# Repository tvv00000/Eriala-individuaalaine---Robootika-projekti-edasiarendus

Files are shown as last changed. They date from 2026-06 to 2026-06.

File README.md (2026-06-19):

MDTJF 2000

MDTJF 2000 on interaktiivne tuumareaktori simulaator. Projekt kasutab füüsilisi juhtpaneele, ekraane, LED-indikaatoreid ja helisignaale, et simuleerida reaktori käivitamist, juhtimist, jahutamist ning elektritootmist.

- `src/` – tarkvara
- `docs/` – juhendid ja tehniline info
- `hardware/` – elektroonika ja skeemid
- `media/` – demonstratsioonid

[demovideo](https://drive.google.com/file/d/1ct23M7h8ehWZ-KBIECmZKTh7m00w4W7L/view?usp=drive_link)

[WOWKWI link simulaatorile ja skeemile](https://wokwi.com/projects/448691473688261633)

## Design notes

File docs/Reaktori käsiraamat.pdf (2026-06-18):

# MDTJF 2000 Reaktori käsiraamat

# Sisukord

Sisukord | 2
Seadme kirjeldus | 3
Paneelide kirjeldused | 4
Fuel Control | 4
Control Rods | 5
Coolant Control | 6
Turbine | 7
Warnings | 8
Protseduurid | 9
Setup | 9
Startup protseduur | 9
Tööprotseduur | 9
Hädaolukorra protseduur | 9
Metainfo | 9

# Seadme kirjeldus

MDTJF 2000 on vesijahtusega, grafiidiga modereeritud väikereaktor. Selle veemahutavus on 2000l ning ettenähtud tööpiirkonnas ta toodab 500-2000MW energiat reaktiivsuse 2000-6000rad juures. Käesolev käsiraamat kirjeldab ära seadme elemendid ning ohutu kasutuse.

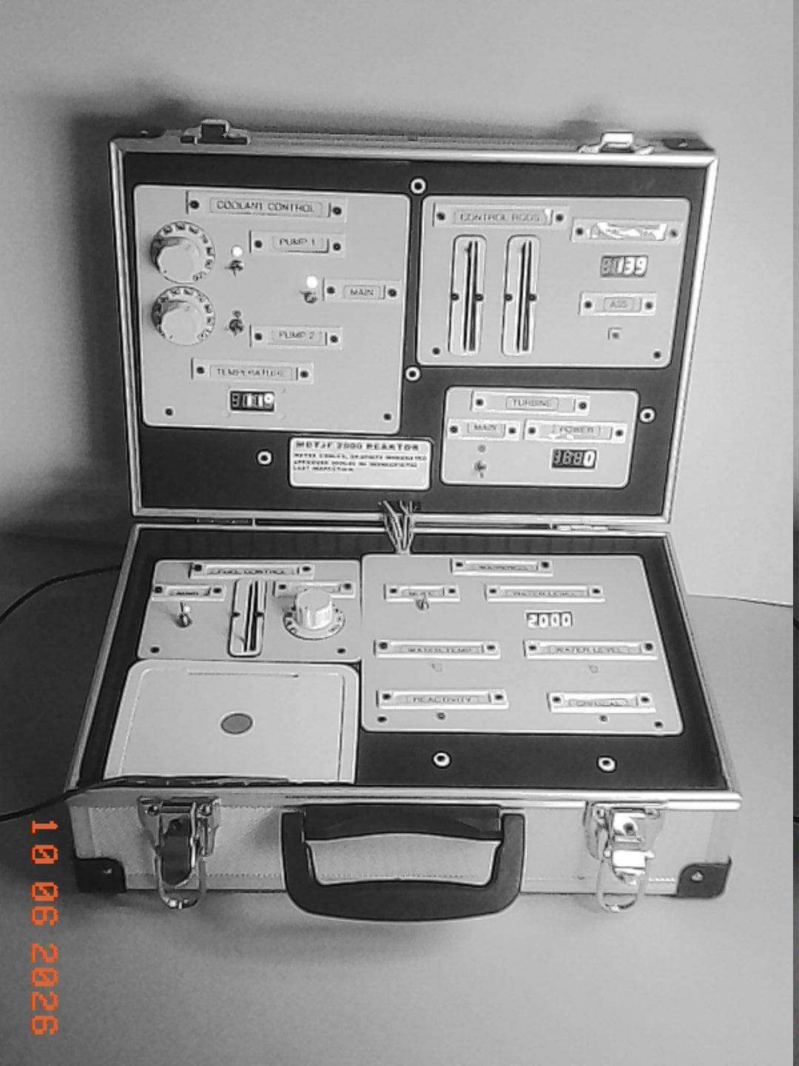
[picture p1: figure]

Pilt 1.1 - Reaktori Kontrollpaneelid

# Paneelide kirjeldused

## Fuel Control

Paneeli funktsioon
Paneel võimaldab juhtida reaktori kütusevarraste asendit ning seeläbi reguleerida tuumas toimuva ahelreaktsiooni intensiivsust. Kütusevarraste sisestamisel reaktori südamikku suureneb reaktsiooni aktiivsus, mille tulemusena eraldub rohkem soojust. Kütusevarraste väljatõmbamisel reaktsiooni intensiivsus väheneb.

Paneeli elementide kirjeldus
- Lüliti MAIN lülitab paneeli sisse/välja.
- Liugur FUEL CONTROL võimaldab muuta kütusevarraste asendit reaktoris.
- Pöördnupp TUNE võimaldab kütusevarraste asendit väikeste sammudega muuta.

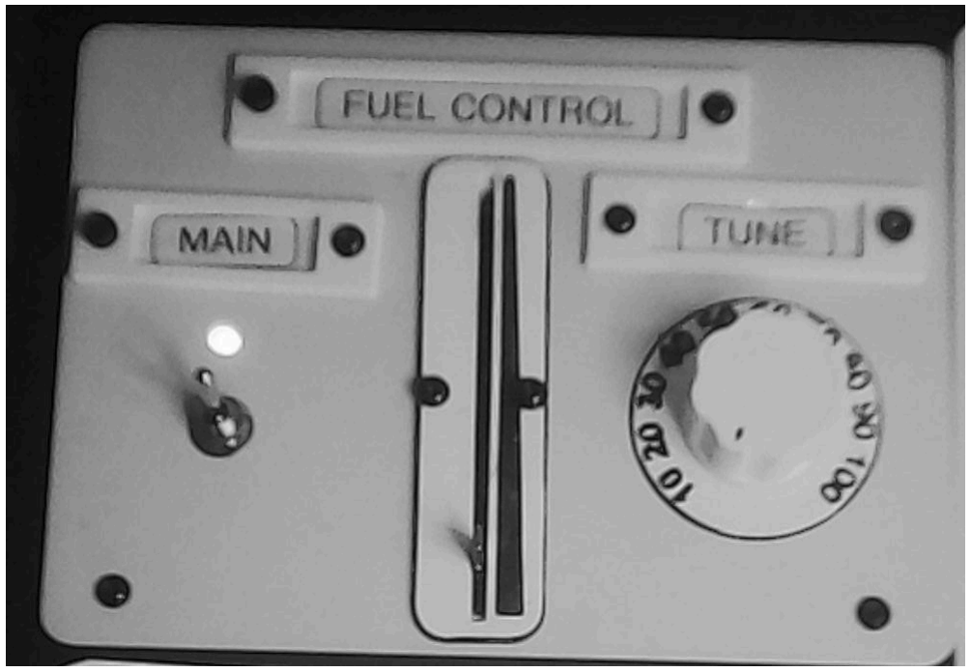
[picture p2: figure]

Pilt 1.2 - Fuel Control Paneel

## Control Rods

Paneeli funktsioon
Paneel võimaldab jälgida ja juhtida reaktori reaktiivsust kontrollvarraste abil. Kontrollvarraste liigutamisega saab reguleerida tuumas toimuva ahelreaktsiooni kiirust ning seeläbi mõjutada reaktori võimsust ja soojuseraldust. Hädaolukorras võimaldab nupp A35 algatada reaktori kiire seiskamise.

Paneeli elementide kirjeldus
- Ekraan REACTIVITY näitab reaktori hetkelise reaktiivsuse ehk ahelreaktsiooni intensiivsuse.
- CONTROL RODS vasak Liugur juhib ühe kolmandiku (1/3) kontrollvarraste asendit.
- CONTROL RODS parem Liugur juhib kahe kolmandiku (2/3) kontrollvarraste asendit.
- Nupp A35 käivitab hädaolukorras reaktori avariiseiskamise protseduuri; tõstab välja kütusevardad, sisestab kontrollvardad ning tõstab pumpade kiiruse maksimumini.

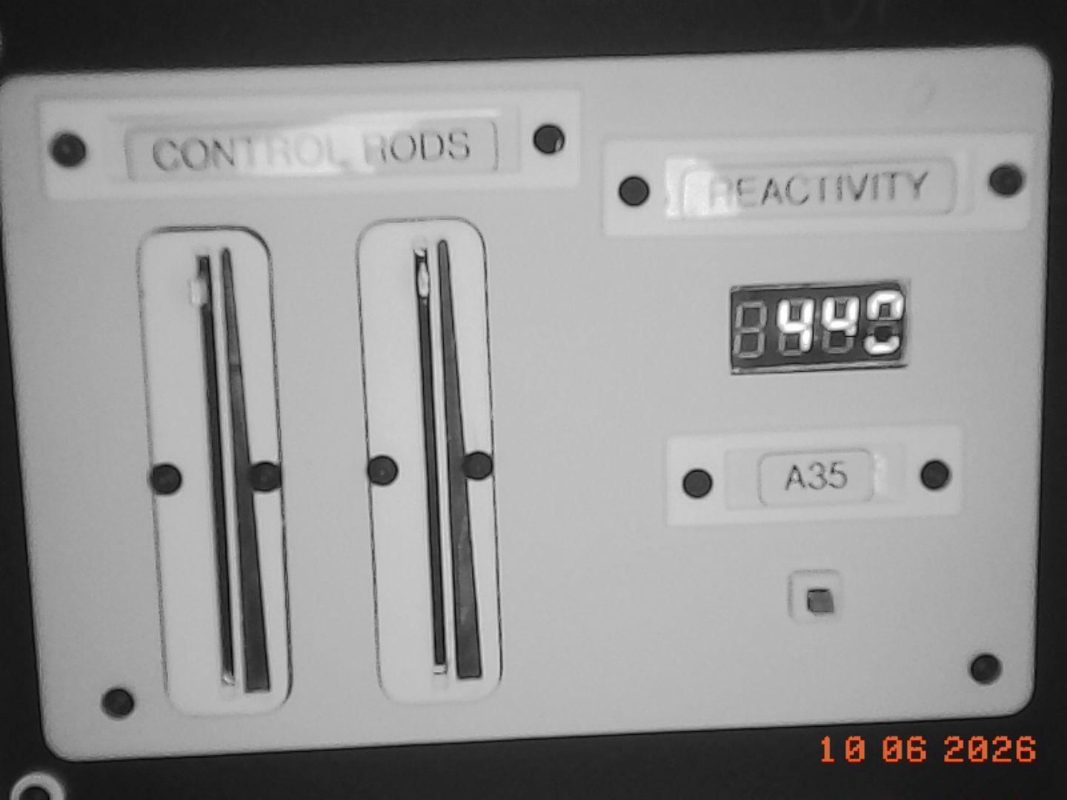
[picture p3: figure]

Pilt 1.3 - Control Rods Paneel

## Coolant Control

Paneeli funktsioon
Paneel võimaldab juhtida jahutussüsteemi pumpade tööd. Selle abil saab pumpasid sisse ja välja lülitada, reguleerida nende töökiirust ning jälgida reaktori veetemperatuuri. Pumpade ülesandeks on tagada tuuma pidev jahutamine ning kompenseerida süsteemist aurustunud vee kadu.

Paneeli elementide kirjeldus
- Lüliti MAIN lülitab paneeli sisse/välja.
- Lülitid PUMP 1 ja PUMP 2 lülitavad vastavad pumpad sisse/välja.
- Pöördnupud PUMP 1 ja PUMP 2 reguleerivad pumpade kiirust.
- Ekraan TEMPERATURE näitab hetke veetemperatuuri.

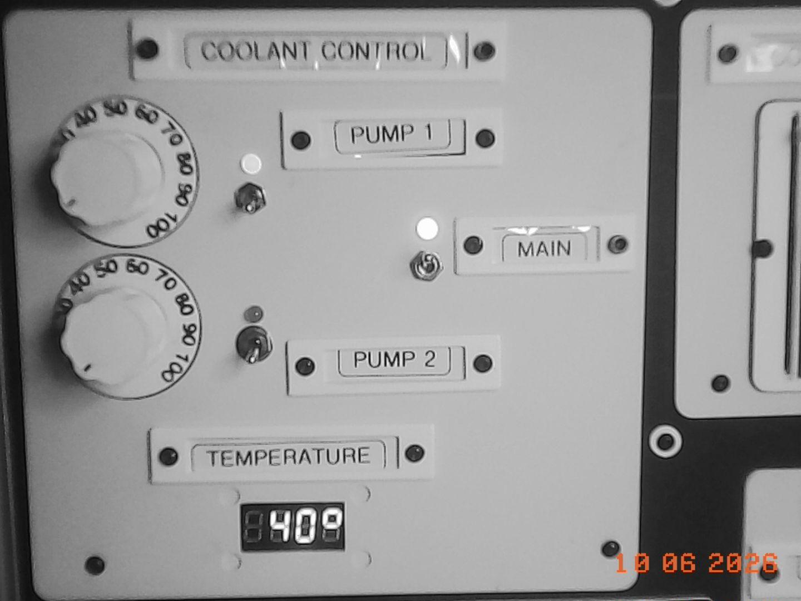
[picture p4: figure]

Pilt 1.4 - Coolant Control Paneel

## Turbine

Paneeli funktsioon
Paneel võimaldab juhtida elektritootmissüsteemi tööd ning jälgida reaktori poolt toodetavat võimsust.

Paneeli elementide kirjeldus
- Lüliti MAIN lülitab turbiinid sisse/välja.
- Ekraan POWER näitab reaktori hetkelise elektrilise võimsuse megavattides.

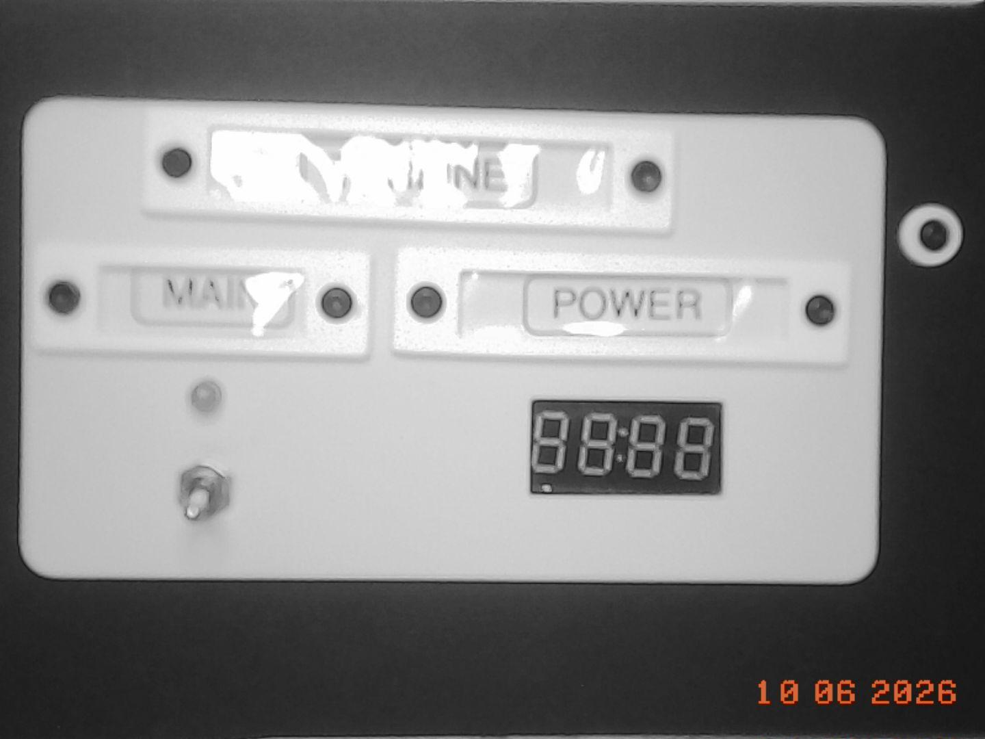
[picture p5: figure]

Pilt 1.5 - Turbine Paneel

## Warnings

Paneeli funktsioon
Paneel võimaldab jälgida reaktori peamisi tööparameetreid ning hoiatab operaatorit võimalike ohuolukordade eest. Selle abil saab jälgida veetaset ja temperatuuri reaktoris, reaktiivsust ja temperatuuri reaktoris ning vaigistada aktiivseid alarmsignaale.

Paneeli elementide kirjeldus
- Lüliti MUTE vaigistab alarmsignaalid.
- Ekraan WATER LEVEL näitab reaktori veetaseme liitrites.
- Märgutuli WATER TEMP süttib, kui vee temperatuur on alla/üle lubatud piirväärtuste (alla 10 kraadi või üle 95 kraadi)
- Märgutuli WATER LEVEL süttib, kui veetase reaktoris langeb ohtlikult madalale (alla 1500).
- Märgutuli REACTIVITY süttib, kui reaktori reaktiivsus ületab ohutud tööpiirid (üle 7000).
- Märgutuli CRITICAL süttib, kui reaktori südamiku temperatuur ületab ohutud piirväärtused.

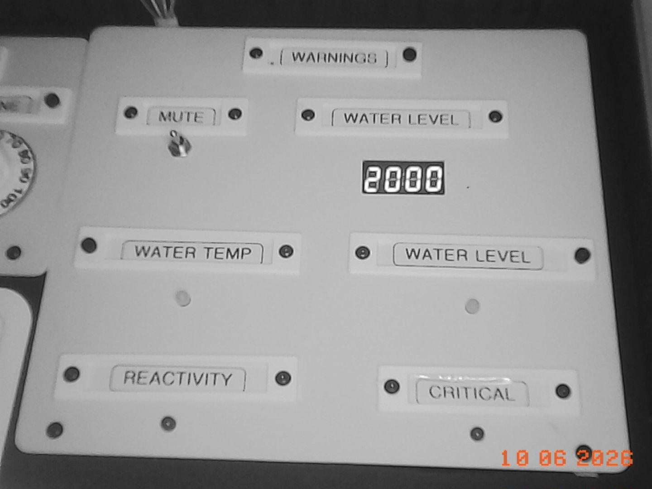
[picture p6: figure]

Pilt 1.6 - Warnings Paneel

# Protseduurid

## Setup

Kõik lülitid/nupud on väljas ja kõik liugurid (liuguril on 100 all ja 0 üleval) on 0s.

## Startup protseduur

1. Lülitada sisse pumba main.
2. Tõsta fuel control tune 50% peale.
3. Lülitada sisse fuel control main.
4. Aeglaselt liigutada kütusevarrast kuni reaktiivsuse ekraan hakkab tõusma.
5. Kui reaktiivsus on tõusnud üle 1000, võib vaikselt sisestada VASAKPOOLSET kontrollvarrast, et kontrollida reaktiivsuse kasvu tõusu.
6. Kui vasakpoolne kontrollvarras on 50% peal, hakata kasutama reaktsiooni kiiruse kontrolliks parempoolset varrast.
7. Kui vee temp jõuab 50c juurde, lülitada sisse pump 1.
8. Veetaseme vähenemisel, tõsta pump 1 kiirust, kuni veekadu lõppeb.
9. Olles jõudnud reaktiivsuseni 3500, hoida seda kuni vee temperatuur jõuba 70cni.
10. Lülitada sisse turbiin.

## Tööprotseduur

Kontrollida reaktsiooni kiirust kasutades kontrollvardaid ja kütusevardaid. Takistada vee kadu kasutades veepumpasid. Kui reaktor toodab energiat, siis veepumbad kasutavad reaktori toodetud energiat. Hoida energia tootlikkus 1500mw peal (+-500mw).

## Hädaolukorra protseduur

Olukorra kontrolli alt väljudes, lülitada sisse nupp A35. See nupp tõstab välja kütusevardad, sisestab kontrollvardad ning tõstab pumpade kiiruse maksimumini.

## Metainfo

Kui pole soovi kasutada veekeetjat, siis mitte pista see stepslisse. Kui tuuma temperatuur jõuab üle 900c või vee temperatuur üle 200c, siis seade teeb ise restarti, andes sellest teada ekraanil oleva tekstiga. Restardi algusest kuni lõpuni on 6 sekundit aega kõik juhtseadmed algasenditesse panna. fuel control main lüliti väljalülitamise järel ei saa restardi järel reaktor enam ise käivituda. Pumpade main väljalülitamise järel ei jahtu vee temperatuur samuti mitte. Reaktori seadeid saab tuunida parameetritega koodis. Kood on kommenteeritud.

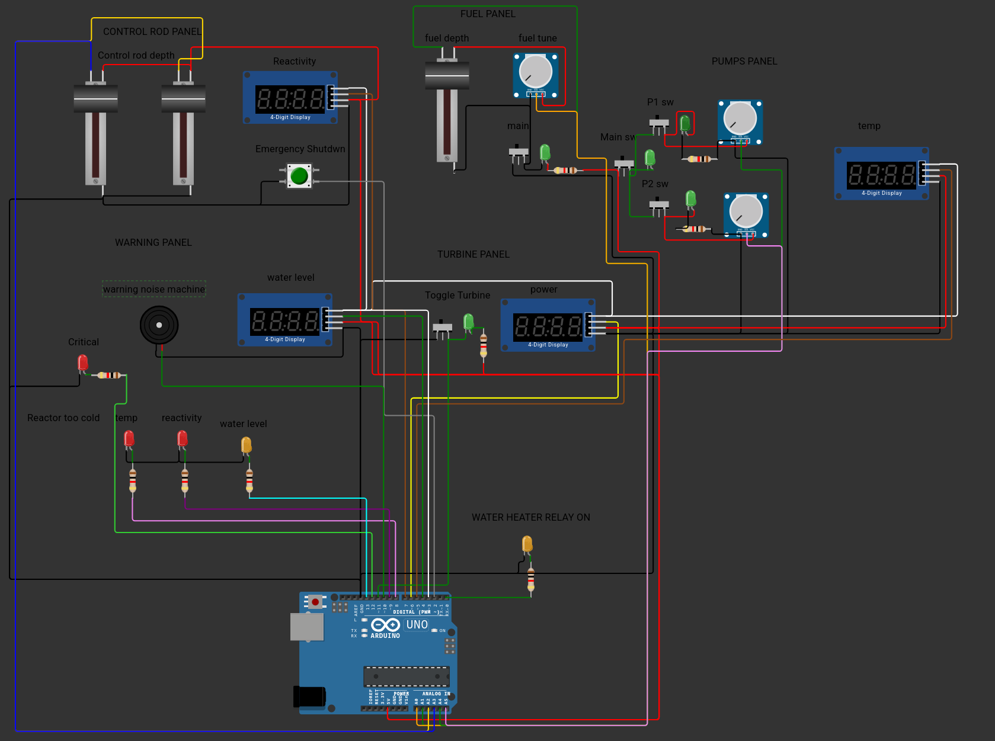
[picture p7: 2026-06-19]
hardware/Reaktor skeem.png

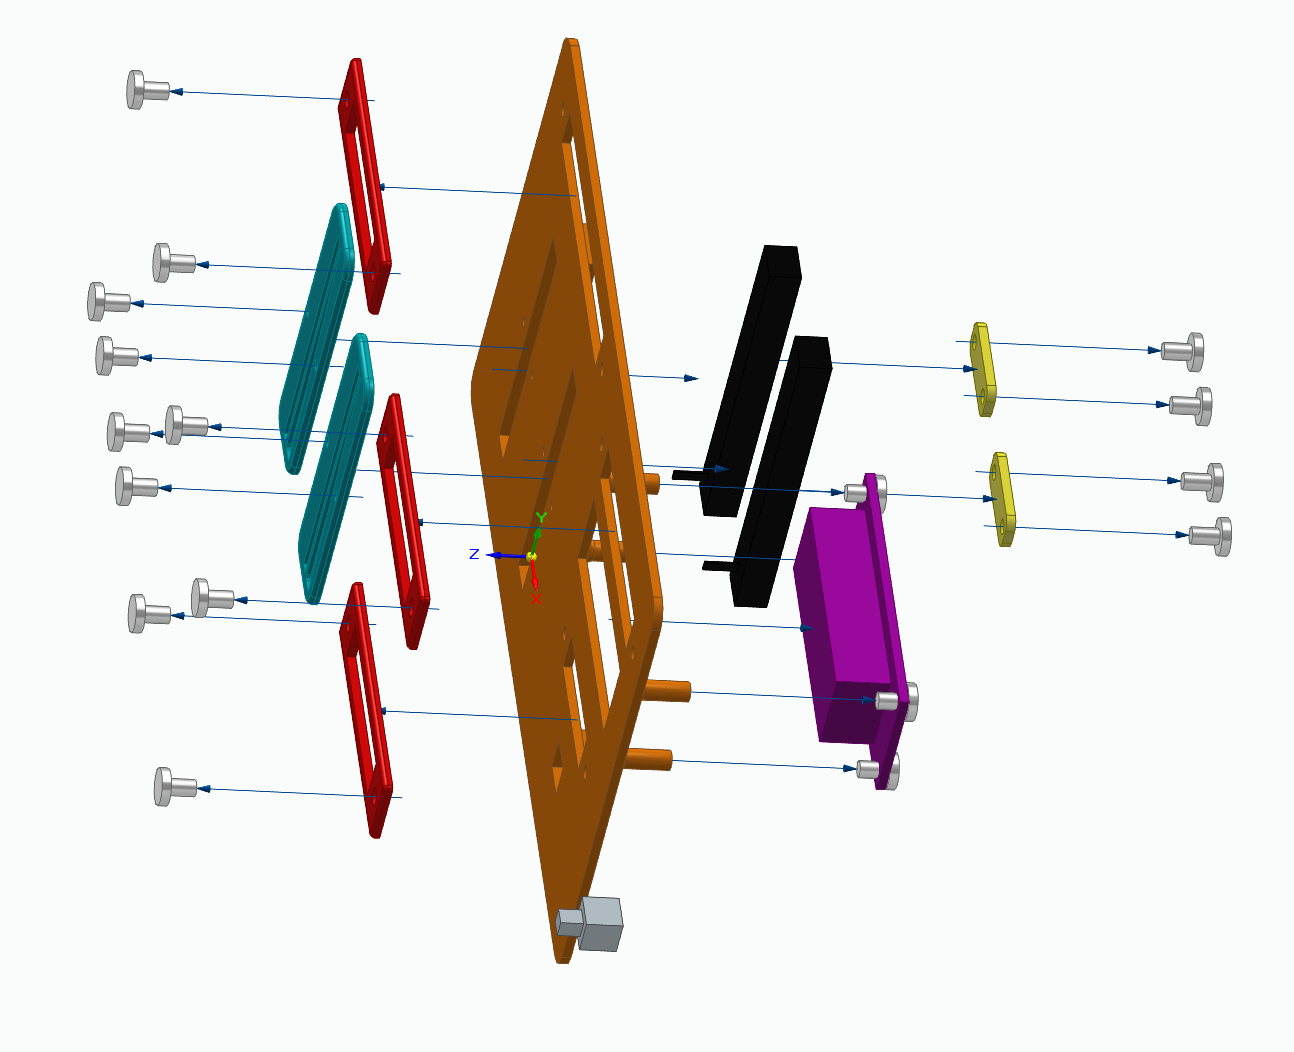
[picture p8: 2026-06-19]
docs/paneeli asm.PNG

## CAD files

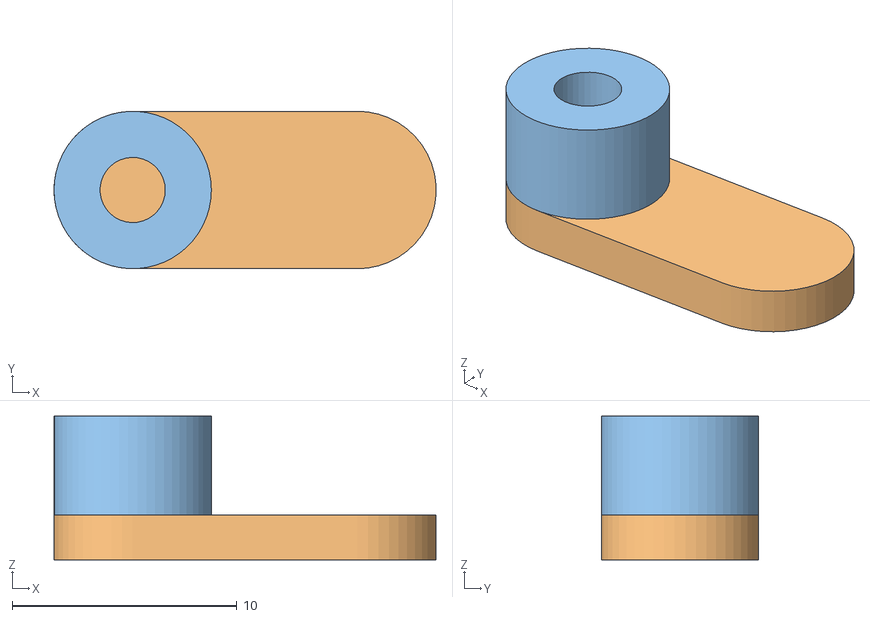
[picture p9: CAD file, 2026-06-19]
hardware/Mounting bracket.obj
17.0 x 7.00 x 6.40

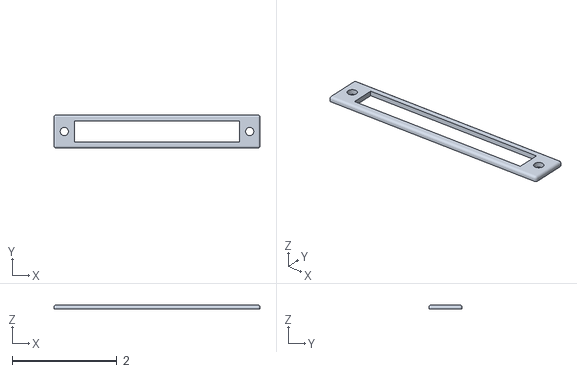
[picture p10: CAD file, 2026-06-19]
hardware/lable cover 80.stl
3.94 x 0.63 x 0.0787

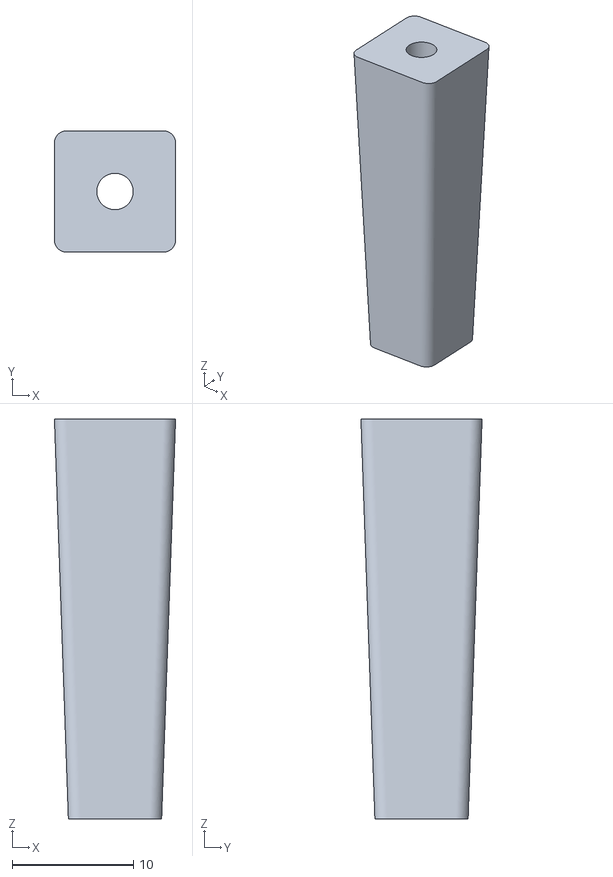
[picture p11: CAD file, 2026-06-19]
hardware/Panel Support 33mm.stl
10.0 x 10.0 x 33.0

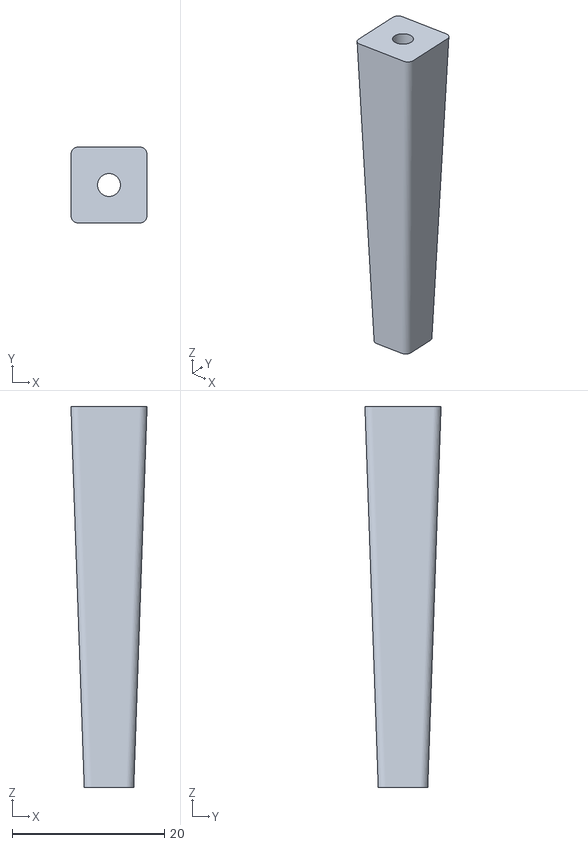
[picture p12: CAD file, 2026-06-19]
hardware/Panel Support 50mm.stl
10.0 x 10.0 x 50.0

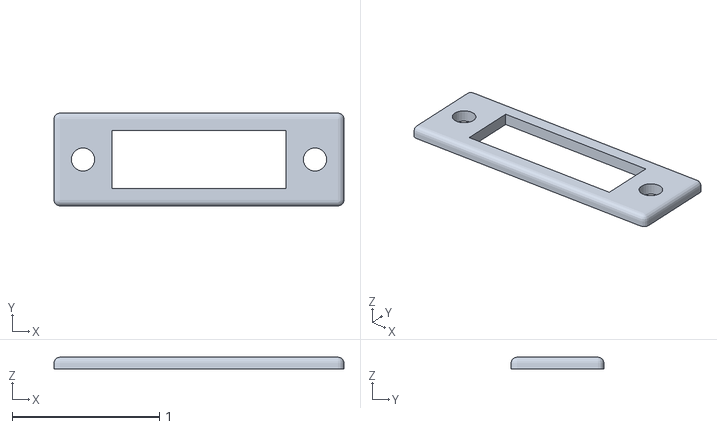
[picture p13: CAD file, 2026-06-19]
hardware/lable cover 30.stl
1.97 x 0.63 x 0.0787

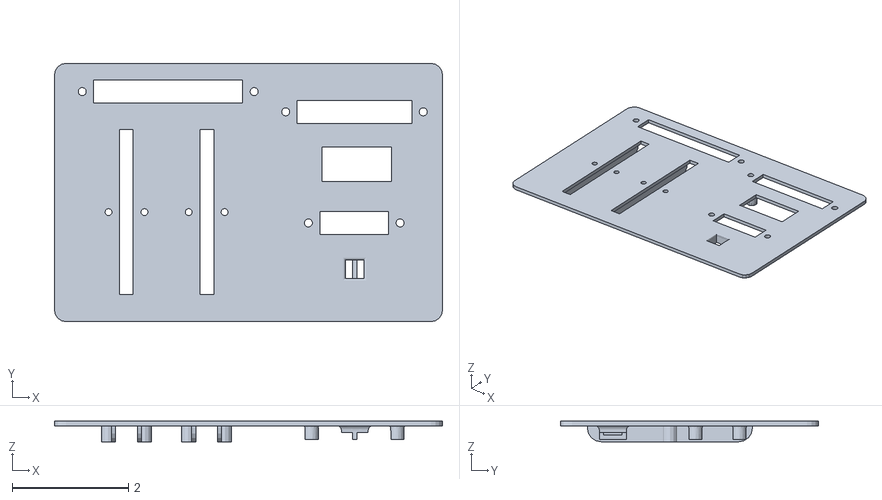
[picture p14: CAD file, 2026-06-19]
hardware/control rod paneel.stl
6.66 x 4.44 x 0.354

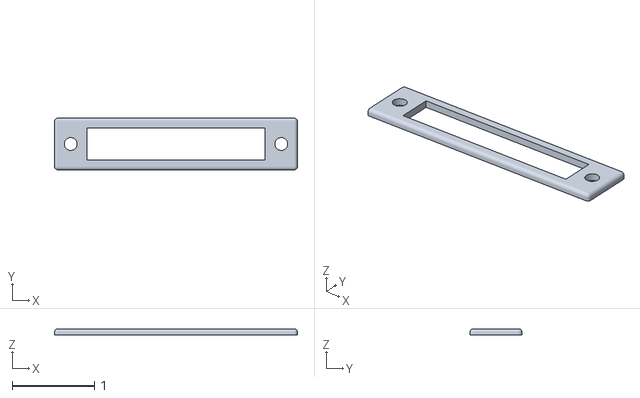
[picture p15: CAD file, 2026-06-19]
hardware/lable cover 55.stl
2.95 x 0.63 x 0.0787

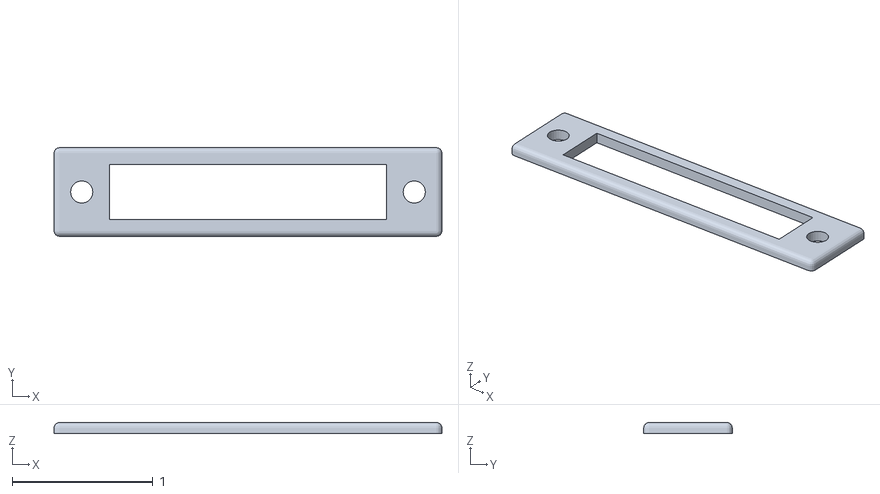
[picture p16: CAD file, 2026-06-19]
hardware/lable cover 50.stl
2.76 x 0.63 x 0.0787

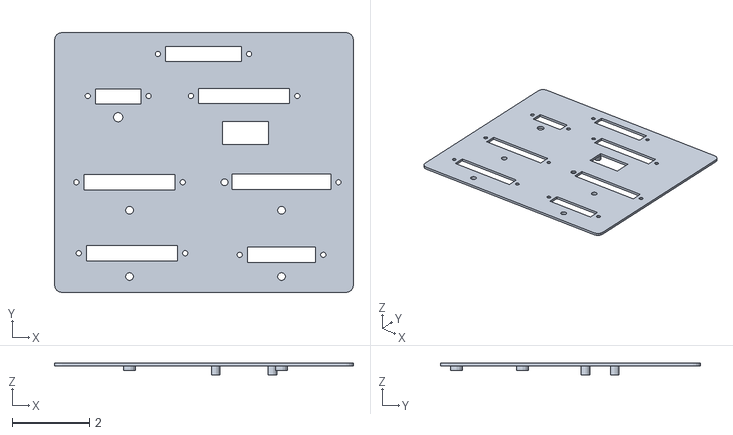
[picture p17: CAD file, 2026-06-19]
hardware/warnings.stl
7.74 x 6.73 x 0.315

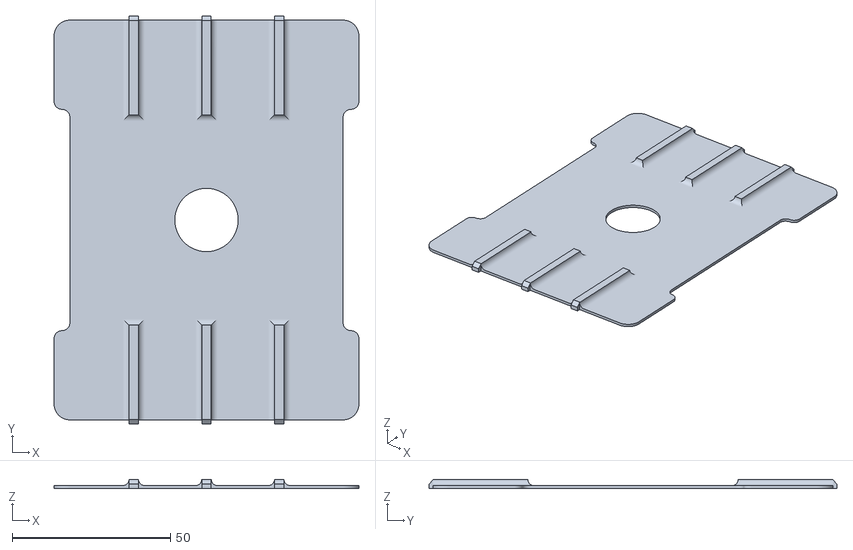
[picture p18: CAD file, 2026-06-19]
hardware/box lid.stl
96.4 x 129.0 x 3.00

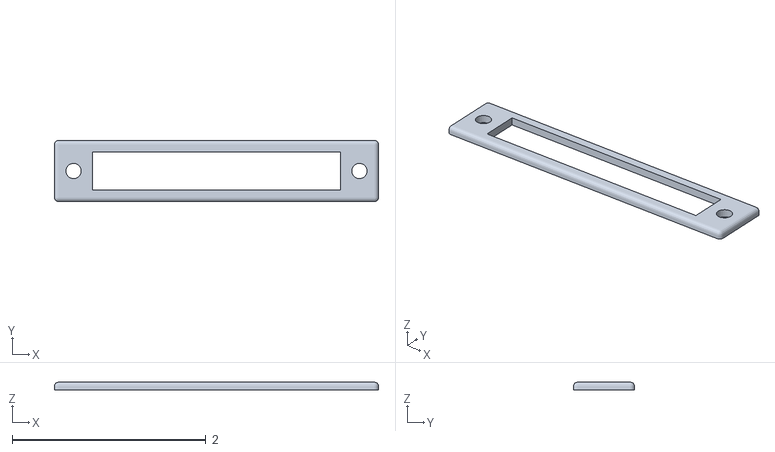
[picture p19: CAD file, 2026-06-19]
hardware/lable cover 65.stl
3.35 x 0.63 x 0.0787

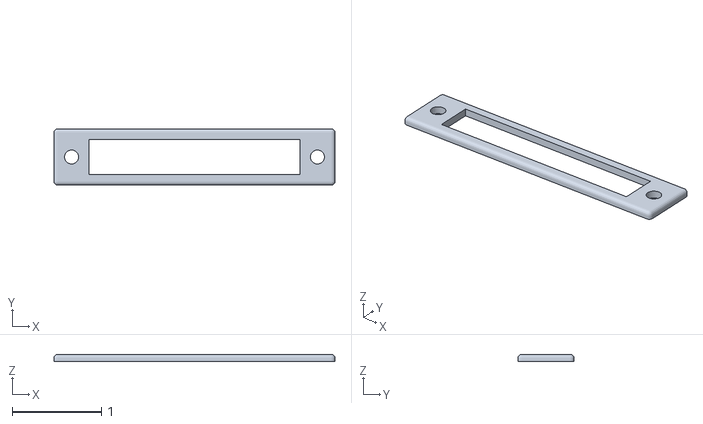
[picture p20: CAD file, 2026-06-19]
hardware/lable cover 60.stl
3.15 x 0.63 x 0.0787

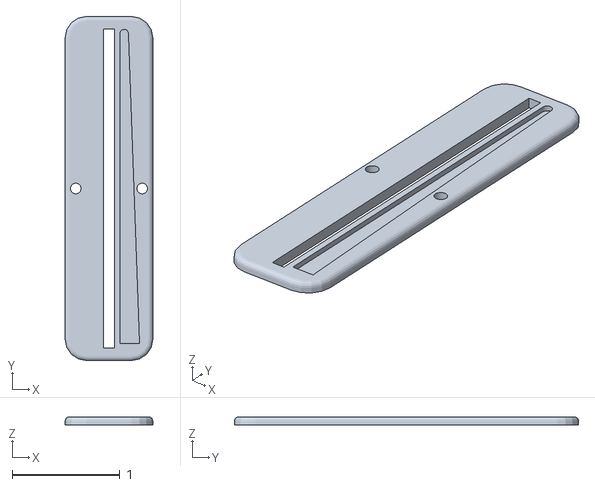
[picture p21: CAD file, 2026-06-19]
hardware/slide pote cover.stl
0.813 x 3.19 x 0.0787

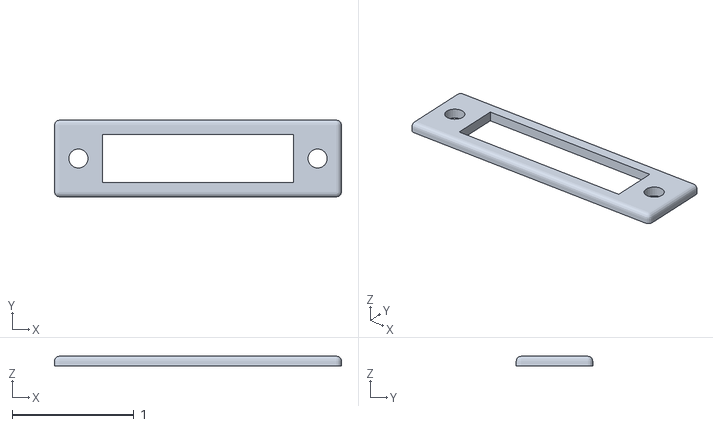
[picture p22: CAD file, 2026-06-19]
hardware/lable cover40.stl
2.36 x 0.63 x 0.0787

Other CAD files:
hardware/lable cover 45.stl
hardware/lable cover 35.stl
hardware/Turbine panel.stl
hardware/LCD MOUNT.stl
hardware/STORAGE BOX top.stl
hardware/STORAGE BOX.stl
hardware/fuel control.stl
hardware/nameplate.stl
hardware/pump paneel.stl
hardware/slide pote bottom.stl
hardware/washer.stl

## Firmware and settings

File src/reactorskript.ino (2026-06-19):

#include <TM1637TinyDisplay.h>
//Pins------------
//fuel rods
#define FUEL1_POT A1
#define FUEL2_POT A0

//control rod
#define CONTROL_ROD_POT1 A3
#define CONTROL_ROD_POT2 A2
#define A35 2

//Pumps
#define PUMP1_POT A5
#define PUMP2_POT A4
#define TURPIN 11

//display
#define DISPLAY_CLOCK 3
#define DISPLAY_REACTIVITY 7
#define DISPLAY_POWER 6
#define DISPLAY_HEAT 5
#define DISPLAY_WATER 4

//warnings
#define WARNING_TEMP 8
#define WARNING_WATER 13
#define WARNING_REACTIVITY 9
#define WARNING_CRIT 12
#define WARNING_PIZO 10

//relay
#define RELAY 1
//end pins ---------


//TÖÖPÕHIMÕTE:
//Reaktiivsus soendab reaktori tuuma, mis soendab omakorda vett ta ümber. Kui vesi jõuab üle 70c, hakkab ta aurustuma
//veeauru tekkimine jahutab vett, vähendab veetaset ning seda saab kasutada energia tootmiseks.
//PUMBAD: Lisavad vett ning jahutavad veetemperatuuri.


//vesi
const double STARTING_WATER = 2000.0;

//reaction parameters
const double FUEL_REACTIVITY = 0.004;  //Kui reaktiivne kütus on
const double CONTROL_ROD_EFFECT = 0.32; //Kui palju kontrollvardad reaktiivsust pärsivad
const double HEAT_RATE = 0.004; //SOOJA GENEREERIMIS EFFEKT radioaktiivsuse poolt, ehk palju tuum soojeneb
const double COOLING_EFFECT = .1; //how chill steam is
const double PUMP_EFFECT = 0.18; //PUMBA EFFEKTIIVSUS
const double PUMP_COOLING_EFFECT = 0.10; //Kui palju pump vett jahutab
const double HEAT_RAD_EFFECT = 0.0003; //kui palju kõrge(vee) temp lisab radiaktiivsusele juurde
const double TRANSFER_RATE = 0.025; //kui hästi tuum veele sooja annab

const double MAX_REACTIVITY = 7000.0; //REAKTIIVSUSE HOIATUS
const double MAX_HEAT = 95.0; //KUUMAHOIATUS
const double MIN_WATERLEVEL = 1500.0; //VEETASEME HOIATUS
const double STARTUP_REACTIVITY = 5.0; //Reaktor üritab end startida selle väärtusega
const double STEAM_EFFECT = 1.4; //kui palju auru tekib vees üle 70c
const double PUMP_POWER_DRAW = 2.0; //palju pumbad voolu võtavad ((pump1 + pump 2) / sellega) (pumbad on 0-100)

//VARS-------------
//reactor
double reactivity = 0.0;
double water_temp = 11.0; //startup heat
double core_temp = 11.0; //startup core temp
double power = 0.0;
int control_rod_depth = 0;
int pump1_speed = 0;
int pump2_speed = 0;
bool turbine_enabled = 0;
double water_level = STARTING_WATER;
int fuel_depth = 0;
int fuel_tune = 0;


//clock
unsigned long lastUpdateTime = 0;
const unsigned long TICKRATE = 500; //Kui tihti seade end updateb.

//hoiatused
bool warning_water = 0;
bool warning_temp = 0;
bool warning_reactivity = 0;
bool warning_crit = 0;

//initialize displays
TM1637TinyDisplay TempDisplay = TM1637TinyDisplay(DISPLAY_CLOCK, DISPLAY_HEAT);
TM1637TinyDisplay ReactivityDisplay = TM1637TinyDisplay(DISPLAY_CLOCK, DISPLAY_REACTIVITY);
TM1637TinyDisplay PowerDisplay = TM1637TinyDisplay(DISPLAY_CLOCK, DISPLAY_POWER);
TM1637TinyDisplay WaterLevelDisplay = TM1637TinyDisplay(DISPLAY_CLOCK, DISPLAY_WATER);

//Toore inputi printout:
bool raw_print = 0; //muuta 1ks kui vaja näha raw printe serialis.

void setup() {
    //initialize serial
    Serial.begin(9600);

    pinMode(TURPIN, INPUT_PULLUP); // pin low = inserted true
    pinMode(A35, INPUT_PULLUP);

    pinMode(WARNING_TEMP, OUTPUT);
    pinMode(WARNING_WATER, OUTPUT);
    pinMode(WARNING_REACTIVITY, OUTPUT);
    pinMode(WARNING_CRIT, OUTPUT);

    TempDisplay.begin();
    ReactivityDisplay.begin();
    PowerDisplay.begin();
    WaterLevelDisplay.begin();

    TempDisplay.flipDisplay(true);
    ReactivityDisplay.flipDisplay(true);
    PowerDisplay.flipDisplay(true);
    WaterLevelDisplay.flipDisplay(true);


    //finish setup message

    Serial.println("Reactor online, weapons online, all systems nominal");
}//end setup



void loop() {


    unsigned long currentTime = millis();
    if(currentTime-lastUpdateTime >= TICKRATE){ //checks if its time to update
        readInputs();
        simulateReactor();
        simulateTurbine();
        printStatus();
        displayInfo();
        alarmSound();
        toggleRelay();

        //restart funktsioon:
        if (core_temp > 900 || water_temp > 210){
            tone(WARNING_PIZO, 3000);
            delay(1000);
            noTone(WARNING_PIZO);
            TempDisplay.showString("----");
            ReactivityDisplay.showString("----");
            WaterLevelDisplay.showString("----");
            PowerDisplay.showString("----");
            delay(1000);
            TempDisplay.showString("REST");
            ReactivityDisplay.showString("ART");
            for(int i = 5; i != 0; i--){
                PowerDisplay.showNumber(i);
                delay(1000);
            }
            NVIC_SystemReset();

        }
        //set current time
        lastUpdateTime = currentTime;
    }
}//end loop

void readInputs(){

    //kui emergency brake on peal siis kõik asjad nulli, meibi lisada ka natuke buusti
    if (digitalRead(A35) == LOW){
        PowerDisplay.showString("A35");

        fuel_depth = 0;
        fuel_tune = 0;

        control_rod_depth = 1500;

        turbine_enabled = 0;

        pump1_speed = 110;
        pump2_speed = 110;

        tone(WARNING_PIZO, 1000);

    } else {
        noTone(WARNING_PIZO);
        turbine_enabled = (digitalRead(TURPIN) == LOW);

        int control1_raw = analogRead(CONTROL_ROD_POT1);
        int control2_raw = analogRead(CONTROL_ROD_POT2);
        int pump1_raw = analogRead(PUMP1_POT);
        int pump2_raw = analogRead(PUMP2_POT);


        int fuel1_raw = analogRead(FUEL1_POT);
        int fuel_tune_raw = analogRead(FUEL2_POT);

        //parandab tagurpidi fuel rawi ära, kui kütuse main on välja lülitatud..
        if(fuel1_raw < 10){
            fuel1_raw = 1023;
        }

        fuel_depth = map(fuel1_raw, 0, 1023, 1023, 0);
        fuel_tune = map(fuel_tune_raw, 0, 1023, 0, 256);

        //Raw printout
        if (raw_print = 1){
            Serial.print("Pump1 / 2 raw: ");
            Serial.print(pump1_raw);
            Serial.print(" / ");
            Serial.print(pump2_raw);
            Serial.print(" | Control 1/2 raw:");
            Serial.print(control1_raw);
            Serial.print(" / ");
            Serial.print(control2_raw);
            Serial.print(" | Fuel 1/tune raw:");
            Serial.print(fuel1_raw);
            Serial.print(" / ");
            Serial.print(fuel_tune_raw);
        }



        int control_rod1_depth = map(control1_raw, 0, 1024, 0, 512);
        int control_rod2_depth = map(control2_raw, 0, 1024, 0, 1024);

        control_rod_depth = control_rod1_depth + control_rod2_depth;

        pump1_speed = map(pump1_raw, 0, 1024, 0, 100);
        pump2_speed = map(pump2_raw, 0, 4095, 0, 100);
    }

}//end readinputs


void simulateReactor(){
    //delta time calculation
    double dt = (double)TICKRATE / 1000.0; //DT delta time
    double dR_dt; //delta taim reaktiivsus ajas


    // --- Reactivity calculation ---
    double rods_reactivity = ((fuel_depth) * FUEL_REACTIVITY) + (fuel_tune * FUEL_REACTIVITY);
    double control_effect = CONTROL_ROD_EFFECT * (double)control_rod_depth;
    double self_sustain = reactivity * (HEAT_RAD_EFFECT * water_temp); //hoiab reaktiivsust ka siis kui kütust pole
    // kickstart
    if (reactivity == 0.0 && fuel_depth > 100) {
        reactivity = STARTUP_REACTIVITY;
    }

    // reactivity growth when all things applied
    dR_dt = (rods_reactivity * sqrt(reactivity + 1.0)) + self_sustain - control_effect;


    reactivity += dR_dt * dt;

    //clamp reactivity to pos.
    if (reactivity < 0.0) reactivity = 0.0;
    //---------------heat simulation-------------

    double dCore_dt =
    (HEAT_RATE * reactivity)
    - (core_temp - water_temp) * 0.05;

    core_temp += dCore_dt * dt;

    // Water heats slowly
    double dWater_dt =
    (core_temp - water_temp) * TRANSFER_RATE
    - ((pump1_speed + pump2_speed) * PUMP_COOLING_EFFECT) / 4.0;

    water_temp += dWater_dt * dt;
    if(water_temp< 1.0) water_temp = 1.0;

}//end simulateReactor

//todo: effektiivsuspiirkond lisada turbiinile sõltuvalt reaktori iseloomust,
void simulateTurbine(){
    double dt = (double)TICKRATE / 1000.0;


    //kui vesi soe tee auru ja vähenda vett
    if (water_temp > 70.0){
        double steam = (water_temp - 70) * STEAM_EFFECT;

        //kui vett on üle miinimumi ära fläshboili seda
        if (water_level > 1000.0){
            if (water_level > STARTING_WATER){
                water_level = STARTING_WATER;
            }

            water_temp = water_temp - COOLING_EFFECT * steam;
            if(water_temp > 100.0){
                water_temp = 100.0;
            }
        }

        double steam_cooling_effect = steam * COOLING_EFFECT;


        //veekadu on aur korda aeg
        double evap_rate = (steam * dt);

        //vesi kaub evap ratega ja tuleb juurde pumbaga
        water_level = water_level - evap_rate + ((pump1_speed + pump2_speed) * PUMP_EFFECT);;

        //clamp water level to min max
        if(water_level < 0.0){
            water_level = 0.0;
        }

        if(turbine_enabled){
            evap_rate = evap_rate * 5;
            power = steam * steam - ((pump1_speed + pump2_speed)/ PUMP_POWER_DRAW);
        } else {
            power = power - (3 * dt);
        }
    }
}//end turbine

void displayInfo(){

    int tempInfo = static_cast<int>(water_temp);
    int reactivityInfo = static_cast<int>(reactivity);
    int powerInfo = static_cast<int>(power);
    int waterLevel = static_cast<int>(water_level);

    tempInfo = constrain(tempInfo, 1, 9999);
    reactivityInfo = constrain(reactivityInfo, 0, 9999);
    powerInfo = constrain(powerInfo, 0, 9999);
    waterLevel = constrain(waterLevel, 0, 9999);

    TempDisplay.showString("\xB0", 1, 3);        // Degree Mark, length=1, position=3 (right)
    TempDisplay.showNumber(tempInfo, false, 3, 0);    // Number, length=3, position=0 (left)

    ReactivityDisplay.showNumber(reactivityInfo);
    PowerDisplay.showNumber(powerInfo);
    WaterLevelDisplay.showNumber(waterLevel);
}

void printStatus() {
    char buffer[128];

    // Header
    Serial.println("+--------------------------------------------------------------------------------+");
    Serial.print("  fuel_depth");
    Serial.print(fuel_depth);
    Serial.print("  control_rod_depth");
    Serial.print(control_rod_depth);
    Serial.print("  pumps");
    Serial.print( pump1_speed);
    Serial.print(", ");
    Serial.print( pump2_speed);
    Serial.println();
    Serial.print("  reactivity");
    Serial.print( reactivity);
    Serial.print("  temp W");
    Serial.print( water_temp);
    Serial.print("  Core Temp");
    Serial.print( core_temp);
    Serial.print("  power");
    Serial.print( power);
    Serial.print("  turbine");
    Serial.print( turbine_enabled);
    Serial.print("  water level");
    Serial.print(water_level);
    Serial.println();
    Serial.println("+--------------------------------------------------------------------------------+");

    // Warnings

    ///PIMEDAS HELENDAMISE HOIATUS ////////////////////
    if (reactivity > MAX_REACTIVITY) {
        warning_reactivity = 1;
        Serial.println(" WARNING: Reactivity runaway imminent!");
    } else{
        warning_reactivity = 0;
    }

    ///HEA LEILI HOIATUS ////////////////////
    if (water_temp > MAX_HEAT || water_temp < 10.0) {
        warning_temp = 1;
        Serial.println(" Water temp warning!");
    } else {
        warning_temp = 0;
    }

    /// HALVA UJUMISE HOIATUS ////////////////////
    if (water_level < MIN_WATERLEVEL) {
        Serial.println("ALERT: Water level low!");
        warning_water = 1;
    } else {
        warning_water = 0;
    }

    ///NO IKKA TÄISHOIATUS ////////////////////
    if (core_temp > 900){
        warning_crit = 1;
    } else {
        warning_crit = 0;
    }

    digitalWrite(WARNING_REACTIVITY, warning_reactivity ? HIGH : LOW);
    digitalWrite(WARNING_TEMP, warning_temp ? HIGH : LOW);
    digitalWrite(WARNING_WATER, warning_water ? HIGH : LOW);
    digitalWrite(WARNING_CRIT, warning_crit ? HIGH : LOW);
}//endprintstatus

void alarmSound() {
    static bool beepState = false;
    static unsigned long lastToggle = 0;

    bool anyWarning =
        warning_water ||
        warning_temp ||
        warning_reactivity ||
        warning_crit;

    // Don't interfere with A35 alarm
    if (digitalRead(A35) == LOW) {
        return;
    }

    if (anyWarning) {
        if (millis() - lastToggle > 500) { // 0.5s on/off
            lastToggle = millis();
            beepState = !beepState;

            if (beepState) {
                tone(WARNING_PIZO, 2000);
            } else {
                noTone(WARNING_PIZO);
            }
        }
    } else {
        noTone(WARNING_PIZO);
        beepState = false;
    }
}

void toggleRelay(){
    static unsigned long cycleStart = 0;
    unsigned long now = millis();

    // Start a new 4-second cycle
    if (now - cycleStart >= 4000) {
        cycleStart = now;
    }
    unsigned long delta = now - cycleStart;
    if(power > 2000){
        digitalWrite(RELAY,HIGH);
        Serial.println("RELAY ON!");

    }else if(power > 1500){
        if(delta < 3000){
            digitalWrite(RELAY,HIGH);
            Serial.println("RELAY ON!");
        }else{
            digitalWrite(RELAY, LOW);
        }

    }else if(power > 1000){
        if(delta < 2000){
            digitalWrite(RELAY,HIGH);
            Serial.println("RELAY ON!");
        }else{
            digitalWrite(RELAY, LOW);
        }

    }else if(power > 500){
        if(delta < 1000){
            digitalWrite(RELAY,HIGH);
            Serial.println("RELAY ON!");
        }else{
            digitalWrite(RELAY, LOW);
        }
    } else{
        digitalWrite(RELAY, LOW);
    }
}

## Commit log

2026-06-19 Replaced EzBuzzer
    Replaced EzBuzzer due to it not working on our arduino.
    [reactorskript.ino]
2026-06-19 add: prinditavate juppide kogus
    [LCD MOUNT.stl, Panel Support 33mm.stl, Panel Support 50mm.stl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]
2026-06-19 add: mounting bracketr
    [Mounting bracket.obj]
